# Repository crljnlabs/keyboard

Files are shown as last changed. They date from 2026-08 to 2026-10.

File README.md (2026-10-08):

# keyboard

The crljn keypad: six keys, a rotary encoder with a push button and a 1.69 inch
display, on an ESP32-S3 Super Mini. This repository holds its firmware and its
circuit board.

Over USB the keypad is a vendor-defined HID device, so no operating system
treats it as a keyboard and nothing it sends ever types into a window. What a
key does is up to the program on the PC,
[anydeck](https://github.com/crljnlabs/anydeck), whose device contract
(`docs/device-protocol.md` there) this firmware keeps to.

- What the keypad says over USB, byte for byte: [docs/hid.md](docs/hid.md)

## What the firmware does

- Reads the six keys and the encoder, and reports them to the PC.
- Tells the PC what it is made of, the display included.
- Shows a status screen of its own: the encoder's position and last direction,
  and which keys are held.
- Logs over the same USB cable, as a serial port.

Not yet: showing on the display what the PC sends.

## Building and flashing

Needs Python 3 and PlatformIO (`pio`). Everything else - the toolchain, the
libraries, esptool - PlatformIO fetches itself on the first build.

```bash
python3 scripts/flash.py
```

The everyday command: compiles, flashes the board and opens the serial monitor.
It remembers the port that worked and only asks again when that one is gone.
`-p <port>` picks a port once, `--no-monitor` leaves the monitor closed.

```bash
python3 scripts/build.py
```

Compiles only, into `build/<timestamp>/`, which is not tracked.

```bash
python3 scripts/deploy.py
```

Publishes a build that already exists as a version, `release/<version>/`, which
is tracked. It never compiles, so the bytes that were tested are the bytes that
get published. It suggests the newest build and the next minor version.

```bash
python3 release/install.py
```

Flashes a published version, the newest unless one is named; `--list` shows
them. Nothing is published yet.

## Technology

- C++ with PlatformIO and the Arduino framework, for the ESP32-S3 Super Mini
  (module ESP32-S3FH4R2: 4 MB flash, 2 MB PSRAM). The platform is pinned,
  `espressif32@6.12.0` with Arduino core 2.0.17, so a build is reproducible.
- USB through TinyUSB (`ARDUINO_USB_MODE=0`), which a vendor-defined HID
  interface needs; the serial port sits next to it on the same device.
- The display, an ST7789 panel, through TFT_eSPI, configured only through build
  flags in `platformio.ini`.

## Where things are

| | |
|---|---|
| `src/` | the firmware |
| `include/pins.h` | every GPIO the firmware touches, and why the pins do not match the schematic's net names |
| `platformio.ini` | the board, the USB setup and the display configuration |
| `docs/` | the USB protocol |
| `kicad/` | schematic, board, 3D model, gerbers and an interactive BOM |
| `scripts/` | building, flashing and publishing |
| `release/` | published versions, and the script that installs them |

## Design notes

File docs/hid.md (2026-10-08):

# USB protocol of the crljn keypad

What this firmware tells the PC about itself, and what it sends, byte for byte.

The rules behind it are not this device's own. A device that is to work with
anydeck keeps to anydeck's device contract, `docs/device-protocol.md` in the
anydeck repository (github.com/crljnlabs/anydeck): why every collection is
vendor-defined, which standard usages anydeck recognises, why the serial number
matters, and how the capability report is built, with all its defaults. This
file is the keypad's answer to it and does not repeat it.

Status in this firmware:

| | |
|---|---|
| report descriptor | offered, 120 bytes |
| report `0x01`, input | sent |
| report `0x10`, capability block | answered |
| report `0x11`, fast buttons | answered and taken, kept in flash |
| report `0x20`, display data | declared, and ignored when it arrives |

What anydeck does with each of them today is in the contract's last section.

## Identity

| | | where it comes from |
|---|---|---|
| vendor id | `0x303A` | the Arduino core's `esp32s3` variant |
| product id | `0x1001` | the Arduino core's `esp32s3` variant |
| manufacturer | `crljn.labs` | `USB_MANUFACTURER` in `platformio.ini` |
| product | `crljn-board` | `USB_PRODUCT` in `platformio.ini` |
| serial number | the chip's MAC address | the Arduino core's default |

The product and the manufacturer are set by this project. The serial number
is the chip's factory MAC address as twelve hex digits - `2884856D6EC0` on the
first unit - so every keypad has its own, which is what the contract asks for.

The vendor and product id are Espressif's generic pair, shared by many ESP32-S3
boards. That does no harm: anydeck does not pick devices by those ids, and the
serial number tells the units apart.

anydeck names a keypad after its product name when it first finds it.

## Report descriptor

120 bytes. Offered by the device at plug-in time. One vendor-defined
application collection, a vendor-defined physical collection for the keys and
one for the encoder, and standard usages on the data items inside.

```c
static const uint8_t kReportDescriptor[] = {
    0x06, 0x00, 0xFF,        // Usage Page (Vendor Defined 0xFF00)
    0x09, 0x01,              // Usage (0x01)
    0xA1, 0x01,              // Collection (Application)

    0x85, 0x01,              //   Report ID (1)

    0x06, 0x00, 0xFF,        //   Usage Page (Vendor Defined 0xFF00)
    0x09, 0x02,              //   Usage (0x02) - the keys
    0xA1, 0x00,              //   Collection (Physical)
    0x05, 0x09,              //     Usage Page (Button)
    0x19, 0x01,              //     Usage Minimum (Button 1)
    0x29, 0x06,              //     Usage Maximum (Button 6)
    0x15, 0x00,              //     Logical Minimum (0)
    0x25, 0x01,              //     Logical Maximum (1)
    0x75, 0x01,              //     Report Size (1)
    0x95, 0x06,              //     Report Count (6)
    0x81, 0x02,              //     Input (Data, Variable, Absolute)
    0x75, 0x02,              //     Report Size (2)
    0x95, 0x01,              //     Report Count (1)
    0x81, 0x03,              //     Input (Constant) - padding to a byte
    0xC0,                    //   End Collection

    0x06, 0x00, 0xFF,        //   Usage Page (Vendor Defined 0xFF00)
    0x09, 0x03,              //   Usage (0x03) - the encoder
    0xA1, 0x00,              //   Collection (Physical)
    0x05, 0x09,              //     Usage Page (Button)
    0x09, 0x07,              //     Usage (Button 7) - the encoder's click
    0x15, 0x00,              //     Logical Minimum (0)
    0x25, 0x01,              //     Logical Maximum (1)
    0x75, 0x01,              //     Report Size (1)
    0x95, 0x01,              //     Report Count (1)
    0x81, 0x02,              //     Input (Data, Variable, Absolute)
    0x75, 0x07,              //     Report Size (7)
    0x95, 0x01,              //     Report Count (1)
    0x81, 0x03,              //     Input (Constant) - padding to a byte
    0x05, 0x01,              //     Usage Page (Generic Desktop)
    0x09, 0x37,              //     Usage (Dial)
    0x15, 0x81,              //     Logical Minimum (-127)
    0x25, 0x7F,              //     Logical Maximum (127)
    0x75, 0x08,              //     Report Size (8)
    0x95, 0x01,              //     Report Count (1)
    0x81, 0x06,              //     Input (Data, Variable, Relative)
    0xC0,                    //   End Collection

    0x85, 0x10,              //   Report ID (0x10) - capability block
    0x06, 0x00, 0xFF,        //   Usage Page (Vendor Defined 0xFF00)
    0x09, 0x10,              //   Usage (0x10)
    0x15, 0x00,              //   Logical Minimum (0)
    0x26, 0xFF, 0x00,        //   Logical Maximum (255)
    0x75, 0x08,              //   Report Size (8)
    0x95, 0x3F,              //   Report Count (63)
    0xB1, 0x02,              //   Feature (Data, Variable, Absolute)

    0x85, 0x11,              //   Report ID (0x11) - fast buttons
    0x09, 0x11,              //   Usage (0x11)
    0x75, 0x08,              //   Report Size (8)
    0x95, 0x01,              //   Report Count (1)
    0xB1, 0x02,              //   Feature (Data, Variable, Absolute)

    0x85, 0x20,              //   Report ID (0x20) - display data, PC -> device
    0x09, 0x20,              //   Usage (0x20)
    0x75, 0x08,              //   Report Size (8)
    0x95, 0x3F,              //   Report Count (63)
    0x91, 0x02,              //   Output (Data, Variable, Absolute)

    0xC0,                    // End Collection
};
```

What anydeck makes of it: six keys, from the six buttons, and one rotary
encoder, from the dial and the button in the same collection.

### Why the keys and the encoder are not labelled `Keypad` and `Dial`

They were once. With the keys' collection labelled `Keypad`, macOS's keyboard
driver took the device and turned its buttons into clicks in the focused
window, although the application collection around it was vendor-defined:
macOS publishes the usage of every application *and* every physical collection,
and its keyboard driver matches on them. Vendor usages `0x02` and `0x03` keep
it out, and cost nothing - what an element is follows from the items inside a
collection, never from its label. `src/keypad_hid.cpp` has the full account.

### Listed three times on macOS

macOS lists every collection usage it finds, not only the application one, so
this device appears **three times** in `hid.enumerate()` - as usages `0x01`,
`0x02` and `0x03` on page `0xFF00` - all carrying the same path. It is one
device, listed once per collection.

## Report 0x01 — input, device to PC, 4 bytes

| Byte | Bits | Meaning |
|---|---|---|
| 0 | 7..0 | report id, always `0x01` |
| 1 | 0..5 | keys SW1..SW6, one bit each, `1` = pressed |
| 1 | 6..7 | padding, always `0` |
| 2 | 0 | encoder push button, `1` = pressed |
| 2 | 1..7 | padding, always `0` |
| 3 | 7..0 | encoder movement since the previous report, signed, `+` = clockwise |

Sent when something changed. Also sent once after start-up, as soon as the PC
has set the device up, with whatever is held at that moment - even if that is
nothing. A program that opens the device only later does not get that first
report; it asks instead. A GET_REPORT for report `0x01` answers with the keys and
the button as they are now and `0` in byte 3 - asking is not turning, and
detents not yet sent still go out with the next report. anydeck asks once,
when it opens the keypad.

Byte 3 is a **difference, not a position**. The firmware adds up detents between
reports. A report takes as many of them as fit - up to ±127 - and leaves the
rest for the next one, so a fast spin arrives in full rather than clipped. A
report counts as sent once it is queued for the endpoint; only one that could
not be queued keeps its state for another try, so no detent is lost and none
arrives twice. Apart from the first report, none is sent for a difference of
zero with no button change.

## Report 0x10 — capability block, feature, read by the PC

Declared as 63 bytes. The firmware answers whenever it is asked, with the 21
bytes it has to say rather than 63 - two entries and the end of the list. The
format allows that: a reader goes by the entries, not by the report's length.

On the wire, after the report id:

```
01 02 01 01                                     device info, 2 bytes
02 0D 18 01 F0 00 01 00 03 0E 46 01 17 01 03    display, 13 bytes
00 00                                           end of list
```

| Entry | Byte | Field | Value on this device |
|---|---|---|---|
| `0x01` device info | 0 | protocol version | `1` |
| | 1 | display entries that follow | `1` |
| `0x02` display | 0..1 | width in pixels | `280` |
| | 2..3 | height in pixels | `240` |
| | 4 | pixel format | `1`, RGB565 |
| | 5 | display index | `0` |
| | 6 | rotation the firmware applies, in 90° steps | `3` |
| | 7 | corner radius in pixels | `43` |
| | 8..9 | physical width, tenths of a millimetre | `326` |
| | 10..11 | physical height, tenths of a millimetre | `279` |
| | 12 | capability flags | `0b0000_0011` |

All 13 bytes of the display entry are sent, so no default applies anywhere.

Width and height are the panel as the firmware draws on it, after rotation `3`.
The panel itself is 240 x 280 (`TFT_WIDTH` and `TFT_HEIGHT` in
`platformio.ini`), and 280 x 240 is the same panel lying on its side; the values
come from `Display::kWidth` and `Display::kHeight`.

The physical size is the 1.69 inch panel's visible area, 32.6 by 27.9 mm in this
orientation. The corner radius of `43` was measured from a photo of the panel -
all four corners came out at 42 to 44 px - and confirmed on the device, where an
arc of that radius ran along the edge of the glass (`Display::kCornerRadius`).

The flags say the backlight can be dimmed (bit 0) and the display takes full
frames (bit 1). Both are true of the panel - the firmware dims the backlight
itself, through PWM - and neither can be reached from the PC yet: there is no
command for the brightness, and nothing receives a frame. The flags describe
the display as it is; using them is the display feed's work.

## Report 0x11 — fast buttons, feature, read and written by the PC

One byte after the report id. A bit stands for a button by its number in the
descriptor, so the contract's rule - bit n for button n + 1 - comes out as:

| Bit | Button | Element |
|---|---|---|
| 0..5 | 1..6 | keys SW1..SW6 |
| 6 | 7 | the encoder's push button |
| 7 | — | always `0` |

`1` is fast, `0` normal, and normal is what a new keypad starts with. Both wait
15 ms (`DebouncedInput`): normal until the contact has been stable that long,
fast after the first edge, which it reports at once. The encoder's turning has
no such setting: its state machine needs no waiting.

A SET_REPORT takes effect at once - a GET_REPORT straight after it answers with
what was set, bit 7 cleared - and the main loop applies it to the inputs and
stores it in flash, NVS namespace `keypad`, key `fast-buttons`. Written only
when the PC sends it, so the flash does not wear; read at every start, so the
keypad keeps the setting after a power cut, with or without a PC.

## Report 0x20 — display data, output, PC to device

Declared as 63 bytes per packet. The firmware ignores whatever arrives on it,
and the framing for pixel data and commands is not specified yet; specifying it
is part of building the display feed. A full frame of this display, 280 x 240 in
RGB565, is 134400 bytes, so it will have to arrive in pieces.

## See also

- anydeck's device contract, `docs/device-protocol.md` in the anydeck
  repository: the rules this file follows, the capability block's format with
  all its defaults, and how anydeck finds and reads a device.
- `src/keypad_hid.cpp`: the descriptor, the capability block and report `0x11`
  as the firmware builds them; `src/debounced_input.h` for the two ways a
  button is debounced.

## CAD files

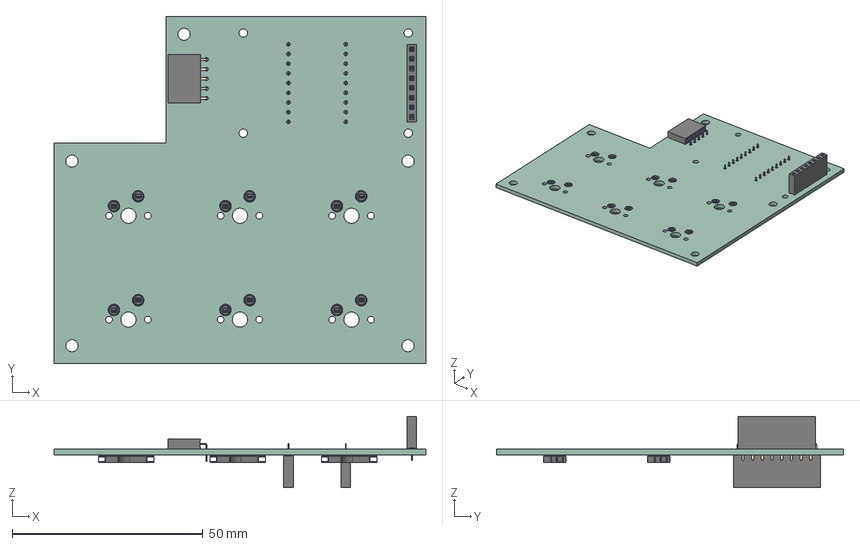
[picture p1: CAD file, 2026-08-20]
kicad/Keypad.step
97.4 x 91.0 x 18.7 mm
SW_Hotswap_Kailh_cp x 6
PinSocket_1x05_P2.54mm_Horizontal
PinSocket_1x08_P2.54mm_Vertical
PinSocket_1x09_P2.54mm_Vertical x 2
Keypad-unsaved-export-8H2TMQ_PCB

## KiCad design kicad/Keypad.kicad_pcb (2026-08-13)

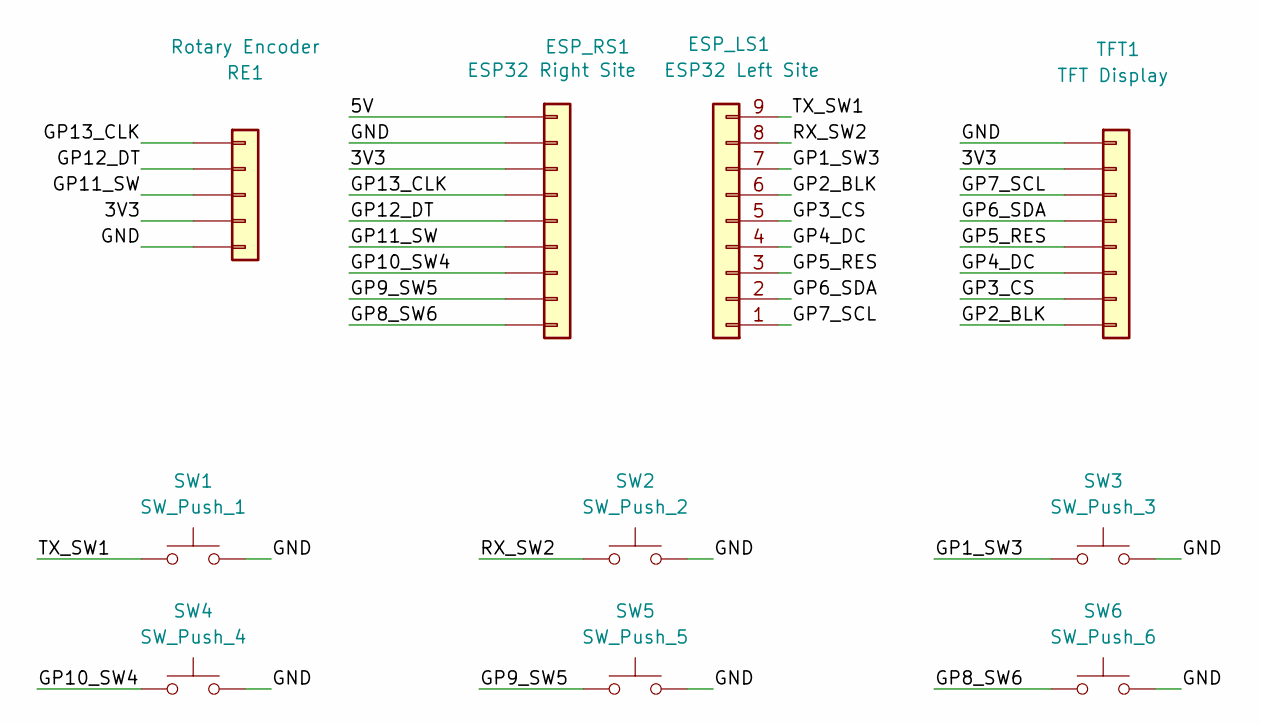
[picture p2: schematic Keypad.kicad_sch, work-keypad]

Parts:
ESP_LS1: ESP32 Left Site; PinSocket_1x09_P2.54mm_Vertical
ESP_RS1: ESP32 Right Site; PinSocket_1x09_P2.54mm_Vertical
RE1: Rotary Encoder; PinSocket_1x05_P2.54mm_Horizontal
SW1: SW_Push_1; SW_Hotswap_Kailh_MX_1.00u
SW2: SW_Push_2; SW_Hotswap_Kailh_MX_1.00u
SW3: SW_Push_3; SW_Hotswap_Kailh_MX_1.00u
SW4: SW_Push_4; SW_Hotswap_Kailh_MX_1.00u
SW5: SW_Push_5; SW_Hotswap_Kailh_MX_1.00u
SW6: SW_Push_6; SW_Hotswap_Kailh_MX_1.00u
TFT1: TFT Display; PinSocket_1x08_P2.54mm_Vertical

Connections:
/3V3: ESP_RS1.3, RE1.4, TFT1.2
/5V: ESP_RS1.1
/GND: ESP_RS1.2, RE1.5, SW1.1, SW2.1, SW3.1, SW4.1, SW5.1, SW6.1, TFT1.1
/GP1_SW3: ESP_LS1.7, SW3.2
/GP2_BLK: ESP_LS1.6, TFT1.8
/GP3_CS: ESP_LS1.5, TFT1.7
/GP4_DC: ESP_LS1.4, TFT1.6
/GP5_RES: ESP_LS1.3, TFT1.5
/GP6_SDA: ESP_LS1.2, TFT1.4
/GP7_SCL: ESP_LS1.1, TFT1.3
/GP8_SW6: ESP_RS1.9, SW6.2
/GP9_SW5: ESP_RS1.8, SW5.2
/GP10_SW4: ESP_RS1.7, SW4.2
/GP11_SW: ESP_RS1.6, RE1.3
/GP12_DT: ESP_RS1.5, RE1.2
/GP13_CLK: ESP_RS1.4, RE1.1
/RX_SW2: ESP_LS1.8, SW2.2
/TX_SW1: ESP_LS1.9, SW1.2

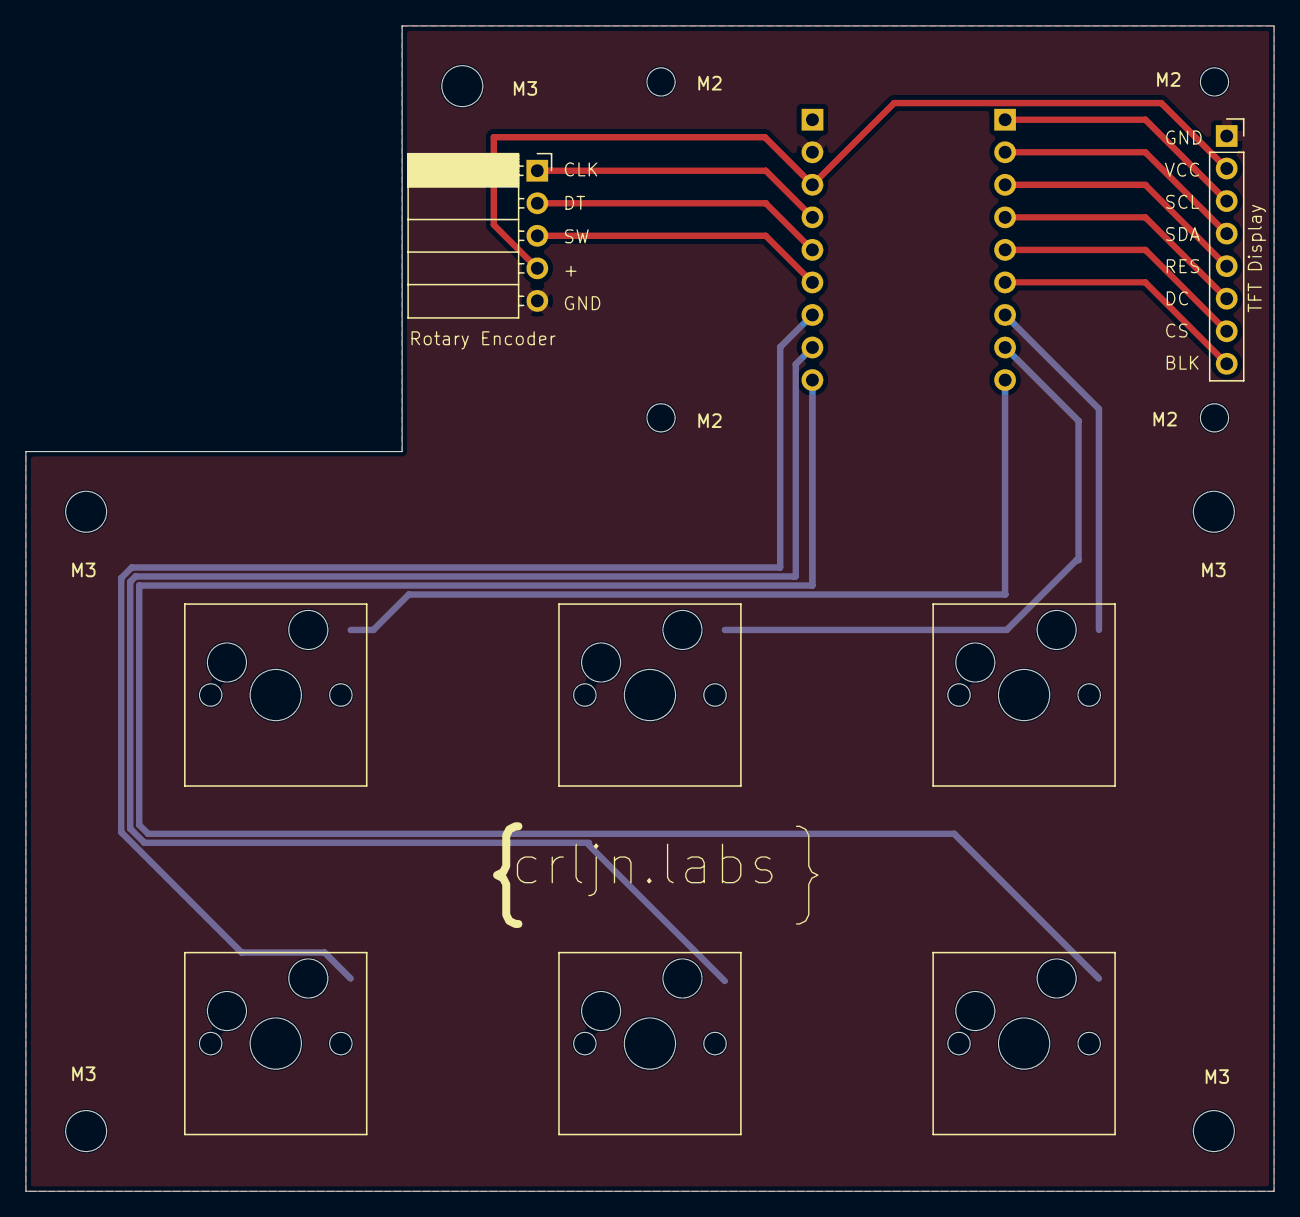
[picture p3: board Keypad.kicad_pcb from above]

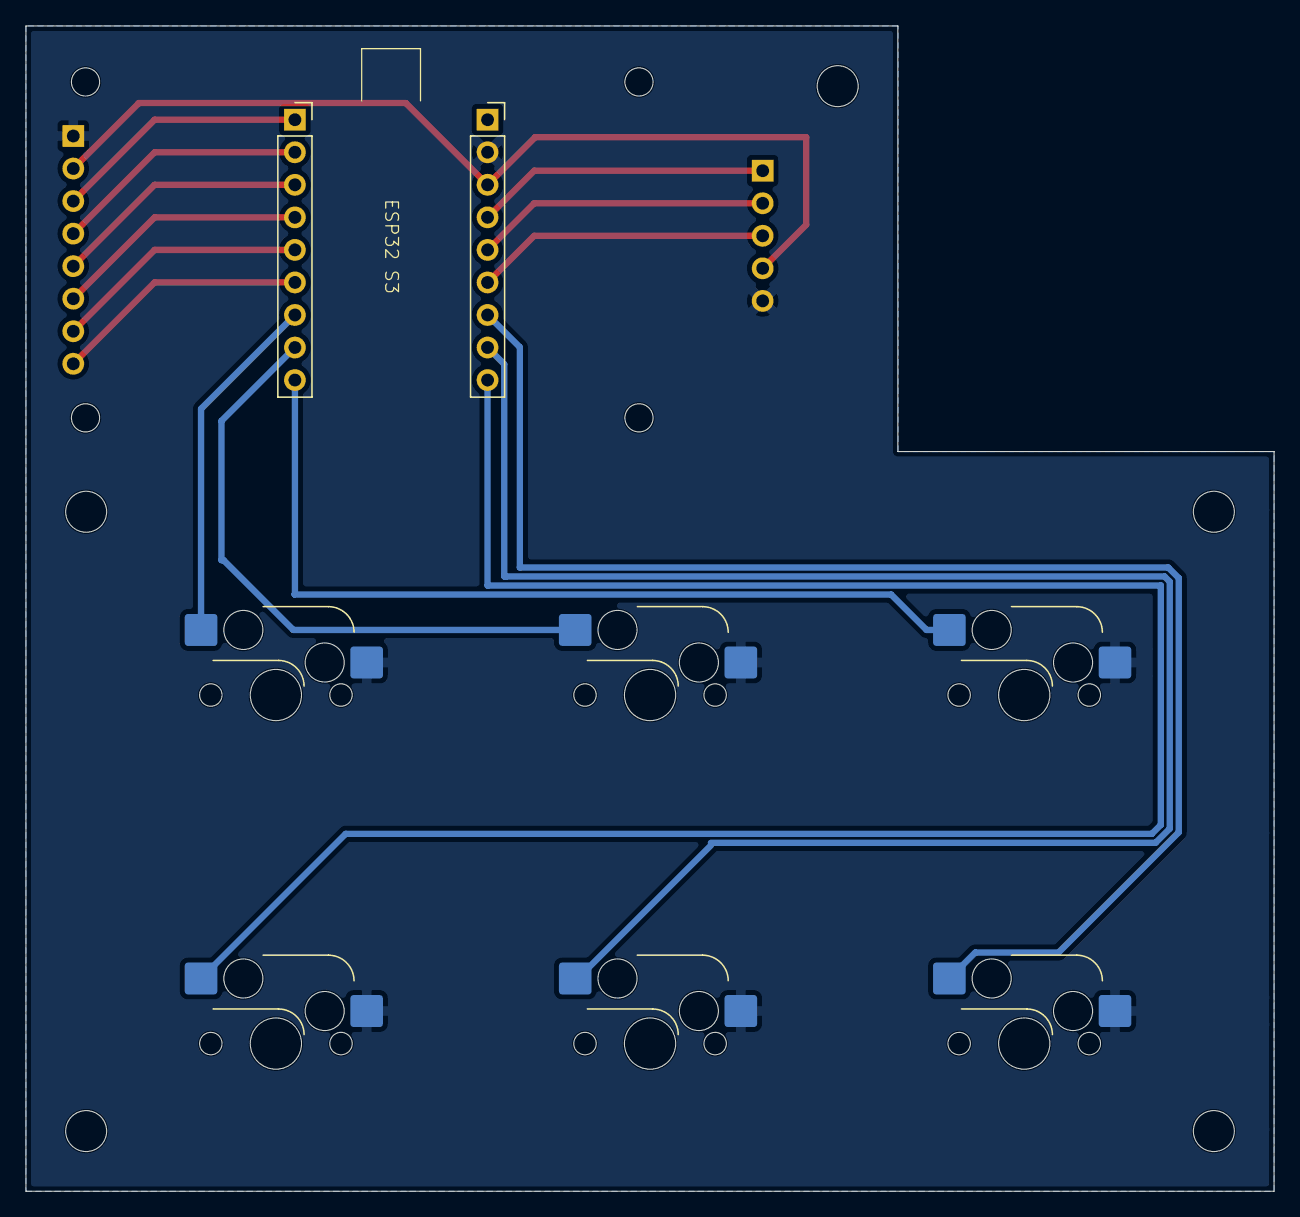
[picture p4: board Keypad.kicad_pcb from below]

Board: 2 copper layers, 97.4 x 91.0 mm, 10 parts (2 on the bottom side), 17 nets.

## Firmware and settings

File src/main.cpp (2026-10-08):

// Firmware entry point.
//
// Reads the six key switches and the rotary encoder, mirrors their state on the
// TFT status screen, and reports them to the PC over a vendor-defined USB HID
// interface. The PC can set single buttons to report at once; the keypad keeps
// that in flash. Receiving display content from the PC is not implemented yet.

#include <Arduino.h>
#include <Preferences.h>

#include "display.h"
#include "keypad_hid.h"
#include "rotary_encoder.h"
#include "status_screen.h"
#include "switches.h"

namespace {

Display display;
StatusScreen screen(display);
RotaryEncoder encoder;
Switches switches;

// Global on purpose, not a local of setup(): its constructor registers the HID
// interface, and the Arduino core starts USB in app_main - before setup() runs.
// A global constructor is the last moment at which the report descriptor can
// still be added.
KeypadHid keypadHid;

constexpr uint8_t kBacklightBrightness = 220;
constexpr uint16_t kBacklightFadeMs = 400;

// Which buttons report at once, kept in flash: the setting outlives a power cut
// and needs no PC to come back.
Preferences settings;
constexpr const char* kSettingsNamespace = "keypad";
constexpr const char* kFastButtonsKey = "fast-buttons";

// Bit n is button n + 1 of the report descriptor: SW1..SW6, then the encoder's
// click.
void applyFastButtons(uint8_t mask) {
  for (uint8_t i = 0; i < Switches::count(); ++i) {
    switches.setFast(i, mask & (1u << i));
  }
  encoder.setButtonFast(mask & (1u << Switches::count()));
}

}  // namespace

void setup() {
  Serial.begin(115200);

  display.begin();
  screen.begin();
  display.fadeBrightness(kBacklightBrightness, kBacklightFadeMs);

  keypadHid.begin();

  encoder.onRotate([](int8_t direction, int32_t position) {
    screen.onEncoderRotate(direction, position);
    keypadHid.addRotation(direction);
  });
  encoder.onButton([](bool pressed) {
    screen.onEncoderButton(pressed);
    keypadHid.setEncoderButton(pressed);
  });
  encoder.begin();

  switches.onEvent([](uint8_t index, bool pressed) {
    screen.onSwitch(index, pressed);
    keypadHid.setKey(index, pressed);
  });
  switches.begin();

  settings.begin(kSettingsNamespace, false);
  const uint8_t fast = settings.getUChar(kFastButtonsKey, 0);
  applyFastButtons(fast);
  keypadHid.setFastButtons(fast);

  Serial.printf("keypad ready: %u switches, 1 encoder, %dx%d display\n", Switches::count(),
                display.width(), display.height());
}

void loop() {
  encoder.update();
  switches.update();
  screen.update();
  keypadHid.update();

  uint8_t fast = 0;
  if (keypadHid.takeFastButtons(fast)) {
    applyFastButtons(fast);
    settings.putUChar(kFastButtonsKey, fast);
  }
}

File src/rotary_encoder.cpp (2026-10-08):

#include "rotary_encoder.h"

namespace {

// Half-step quadrature transition table (Ben Buxton, "Rotary encoder, state
// machine implementation", the half-step variant). Row = current state, column
// = the new pin levels as (B << 1) | A. A cell holds the follow-up state, with
// kDirCw / kDirCcw set in the upper bits when a detent was completed.
//
// Half-step because the encoder on this board clicks twice per quadrature
// cycle: it rests with both lines high, and again with both lines low. A
// full-step table only completes at one of the two, so it counted every second
// click. This one completes at both - one step per click.
//
// A step is still only emitted after the lines passed through the level in
// between, so a contact that rattles between two levels keeps falling back to
// the rest it came from.
constexpr uint8_t kRestHigh = 0x0;     // both lines high
constexpr uint8_t kCcwBegin = 0x1;     // out of the high rest, counter-clockwise
constexpr uint8_t kCwBegin = 0x2;      // out of the high rest, clockwise
constexpr uint8_t kRestLow = 0x3;      // both lines low
constexpr uint8_t kCwBeginLow = 0x4;   // out of the low rest, clockwise
constexpr uint8_t kCcwBeginLow = 0x5;  // out of the low rest, counter-clockwise

constexpr uint8_t kDirCw = 0x10;
constexpr uint8_t kDirCcw = 0x20;
constexpr uint8_t kStateMask = 0x0f;
constexpr uint8_t kDirMask = 0x30;

const uint8_t kTransitions[6][4] = {
    // kRestHigh
    {kRestLow, kCwBegin, kCcwBegin, kRestHigh},
    // kCcwBegin
    {static_cast<uint8_t>(kRestLow | kDirCcw), kRestHigh, kCcwBegin, kRestHigh},
    // kCwBegin
    {static_cast<uint8_t>(kRestLow | kDirCw), kCwBegin, kRestHigh, kRestHigh},
    // kRestLow
    {kRestLow, kCcwBeginLow, kCwBeginLow, kRestHigh},
    // kCwBeginLow
    {kRestLow, kRestLow, kCwBeginLow, static_cast<uint8_t>(kRestHigh | kDirCw)},
    // kCcwBeginLow
    {kRestLow, kCcwBeginLow, kRestLow, static_cast<uint8_t>(kRestHigh | kDirCcw)},
};

}  // namespace

void RotaryEncoder::begin() {
  // The module carries its own pull-ups, but enabling the internal ones keeps
  // the lines defined even when a bare encoder without the breakout is wired
  // up.
  pinMode(pins::kEncoderA, INPUT_PULLUP);
  pinMode(pins::kEncoderB, INPUT_PULLUP);
  button_.begin(pins::kEncoderButton);

  // Start at the rest the knob is actually in. Either is a detent, and the
  // table only leaves a rest through the level in between, so starting at the
  // other one would cost the first click.
  state_ = sampleLevels() == 0 ? kRestLow : kRestHigh;

  attachInterruptArg(digitalPinToInterrupt(pins::kEncoderA), onQuadratureEdge, this, CHANGE);
  attachInterruptArg(digitalPinToInterrupt(pins::kEncoderB), onQuadratureEdge, this, CHANGE);
}

void IRAM_ATTR RotaryEncoder::onQuadratureEdge(void* arg) {
  static_cast<RotaryEncoder*>(arg)->decode();
}

uint8_t IRAM_ATTR RotaryEncoder::sampleLevels() {
  // The transition table is written for (B << 1) | A. On this board CLK and DT
  // reach the MCU the other way round, which made a clockwise turn count down.
  // Sampling the two swapped fixes the direction at its source, so both the
  // table and the reported sign stay canonical - negating the result afterwards
  // would work too, but then every reader has to know about the correction.
  return (digitalRead(pins::kEncoderA) << 1) | digitalRead(pins::kEncoderB);
}

void IRAM_ATTR RotaryEncoder::decode() {
  const uint8_t levels = sampleLevels();
  const uint8_t next = kTransitions[state_ & kStateMask][levels];
  state_ = next & kStateMask;

  const uint8_t direction = next & kDirMask;
  if (direction == 0) {
    return;
  }

  portENTER_CRITICAL_ISR(&lock_);
  pendingSteps_ += (direction == kDirCw) ? 1 : -1;
  portEXIT_CRITICAL_ISR(&lock_);
}

void RotaryEncoder::update() {
  // Take the whole batch at once so no step decoded while reporting is lost.
  portENTER_CRITICAL(&lock_);
  const int32_t steps = pendingSteps_;
  pendingSteps_ = 0;
  portEXIT_CRITICAL(&lock_);

  // Report every detent separately, so a consumer that maps detents to key
  // repeats sees the same count regardless of how long the loop was busy.
  if (steps != 0) {
    const int8_t direction = steps > 0 ? 1 : -1;
    const int32_t count = steps > 0 ? steps : -steps;
    for (int32_t i = 0; i < count; ++i) {
      position_ += direction;
      if (rotationCallback_) {
        rotationCallback_(direction, position_);
      }
    }
  }

  const DebouncedInput::Event event = button_.update();
  if (event != DebouncedInput::Event::kNone && buttonCallback_) {
    buttonCallback_(event == DebouncedInput::Event::kPressed);
  }
}

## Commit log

2026-08-13 Initialize program
    [Keypad-B_Cu.gbr, Keypad-B_Mask.gbr, Keypad-B_Paste.gbr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]
2026-08-20 add step file
    [Keypad.step]
2026-08-23 feat: read the switches and encoder, and show them on the display
    Brings the hardware up: the six key switches, the rotary encoder with its
    push button, and the ST7789 panel, each behind a class that hides how the
    part is wired and exposes what it does.
    pins.h every GPIO the firmware touches, in one place
    DebouncedInput one active-low contact, debounced by sampling
    Switches the six keys, reporting press/release events
    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
2026-08-24 feat: report keys and encoder to the PC over vendor-defined HID
    Adds the USB interface the anydeck application reads. The device is one
    vendor-defined application collection, so no operating system claims it
    and no key press is injected into whatever window happens to be focused.
    Inside that collection every item uses a standard usage, so software that
    has never heard of this device can still tell the six keys and the encoder
    apart. The byte layouts are specified in hid.md.
    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
2026-10-01 fix: the first counter-clockwise detent after power-up counts
    begin() seeded the decoder's state with the pin levels it read. Levels and
    states are different things that happen to share numbers: at a detent both
    lines are high, level 3, and 3 in the transition table is kCwNext - a
    clockwise turn already under way. So the first counter-clockwise detent after
    every power-up or reset read as that turn being undone, and nothing was
    reported; two of them came out as one.
    The decoder now starts where the table rests between detents, kStart,
    whatever the lines read.
    Checked with the real rotary_encoder.cpp compiled on the host against a
    stand-in for the Arduino calls, feeding it the pin sequences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
    [rotary_encoder.cpp]
2026-10-02 fix: a rotation reaches the PC once, even when the host acknowledges late
    USBHID::SendReport() queues the report and then waits up to 100 ms for the
    host to collect it. When that wait runs out it answers false - with the
    report already queued and on its way. update() took false for "nothing went
    out", kept the rotation, and sent it again on the next pass: the PC got the
    same detents twice. Waiting longer would only make it rarer and hold the loop
    longer.
    The report is now handed to tud_hid_n_report() directly, which queues it and
    answers at once. False there really means nothing went out - the endpoint is
    still busy or the host is not listening - and only then is the state kept for
    the next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
    [keypad_hid.cpp]
2026-10-02 feat: the keypad calls itself crljn-board over USB
    The firmware never named the device, so the Arduino core used the board
    definition's name for the USB product string: "Espressif ESP32-S3-DevKitC-1-N8
    (8 MB QD, No PSRAM)" - the wrong board, and what anydeck showed as the name of
    every new keypad.
    USB_PRODUCT is now set in the build flags. The core only falls back to the
    board's name when it is not defined. The manufacturer string and the serial
    number, which the core derives from the chip's MAC address, stay as they were -
    so the identity anydeck stores a keypad under does not change, only the name a
    newly found one is given.
    Checked in the build: the define reaches the compiler as
    USB_PR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
2026-10-02 docs: hid.md describes this keypad, the rules live in anydeck
    The rules any device keeps to - vendor-defined collections, standard usages
    inside, identity, the capability report's format and defaults - are anydeck's
    device contract now, docs/device-protocol.md in the anydeck repository. This
    file keeps what only this keypad says, and corrects what the old one got wrong:
    - status: what the firmware does with each report, and nothing claimed for
    anydeck that it does not do
    - the collection labels are vendor usages because macOS's keyboard driver took
    the device while they were not, not because nothing reads them
    - the USB identity and where each part of it comes from
    - the one input repor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
2026-10-02 docs: the backlight is on GPIO4, not GPIO2
    GPIO2 is the display's DC line (TFT_DC=2 below). include/pins.h has the
    backlight as kTftBacklight = 4, and that is the pin the Display class attaches
    its PWM channel to.
2026-10-02 docs: a README that says what the keypad is and how to flash it
    The README was a heading. It now says what the keypad is and that anydeck's
    device contract is what it keeps to, what the firmware does and does not do
    yet, how the four scripts are used, and where things are.
    The firmware's technology - C++ with PlatformIO for the ESP32-S3 Super Mini -
    was written down in anydeck's requirements. It is this repository's decision,
    so it is here now, with the pinned platform and the USB and display stacks.
2026-10-02 docs: releases are made by deploy.py, install.py says so
    install.py pointed at build.py, both in its docstring and in the message it
    prints when there is nothing to install. build.py only compiles into build/;
    publishing a build to release/ is deploy.py's job.
2026-10-03 fix: no click is lost after power-up, wherever the knob rests
    The encoder on this board clicks twice per quadrature cycle: it rests with both
    lines high, or with both low. The previous fix started the decoder at kStart,
    which only fits the first. Started with both lines low, the first step in
    either direction took three clicks instead of two - before that fix as well.
    begin() now starts at a new state, kMiddle, when both lines are low: halfway
    through a cycle with no direction known yet, which kCwNext and kCcwNext, the
    table's own "both low" states, each already assume. The first step then comes
    at the next rest with both lines high, where every later step comes too.
    Simulated on the PC wi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
    [rotary_encoder.cpp]
2026-10-03 revert: the encoder starts at kStart again, whatever the lines read
    This reverts 8d55c31 ("fix: no click is lost after power-up, wherever the knob
    rests"). On the real keypad the encoder counted nonsense with it, and before it
    counted right - so it goes, the header comment and the line in docs/hid.md with
    it, until what happened on the hardware is understood. The simulation it was
    checked against did not show it, which says the simulation assumed something
    about this encoder that is not true.
    [rotary_encoder.cpp]
2026-10-03 feat: the keypad says crljn.labs made it, not Espressif
    The USB manufacturer string names who made the device, and the Arduino core's
    default named who made its chip - "Espressif Systems", which the vendor id
    0x303A says already. USB_MANUFACTURER is crljn.labs now, as the LICENSE has
    it, set next to the product name in platformio.ini. docs/hid.md says so.
    Checked: the build carries both strings.
2026-10-03 fix: flashing goes straight to download mode on the board's own USB port
    flash.py first let esptool reset the board through the app's own USB port.
    With this firmware that never reached the bootloader: every flash sat through
    a long "Connecting...", failed, and then said "the app is most likely crashing
    and tearing its USB port down" - which it was not - before the 1200 baud touch
    did the job. On the board's own port the touch comes first now. A port that is
    not the board's own, a USB-to-UART bridge on another board, is still tried
    directly first, and its failure is reported as what it is.
    Checked with the ports and esptool stood in, no hardware: the app's port goes
    straight to download mod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
2026-10-03 feat: the encoder counts one step per click
    The encoder clicks twice per quadrature cycle - it rests with both lines
    high and again with both low - and the full-step table only completed a
    step at one of the two, so every second click was lost. The half-step
    variant of the same table completes at both. begin() starts at whichever
    rest the knob is in.
    Simulated on the PC against the previous table, position after each of
    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
2026-10-04 feat: the keypad answers when asked where it stands
    A GET_REPORT for input report 0x01 - which the Arduino core routes to
    _onGetFeature like every GET_REPORT - now answers with the keys and the
    encoder button as they are, and 0 for the rotation: asking is not turning,
    and detents not yet sent still go with the next report. anydeck asks once
    when it opens the keypad, so a program that starts late knows what is held.
2026-10-08 feat: single buttons can report at once, set by the PC and kept in flash
    Feature report 0x11 holds one bit per button, bit n for button n + 1: the six
    keys and the encoder's click. A fast button reports its first edge straight
    away and ignores the contact for the 15 ms after it, instead of waiting until
    the contact has been stable for 15 ms. The bounce is swallowed either way; a
    fast press arrives 15 ms sooner, and a glitch on the line counts as a press.
    The PC reads the report and sets it. The keypad takes a new setting at once,
    so reading it back shows what took effect, applies it from the main loop and
    stores it in NVS, so it survives a power cut without a PC. Nothing changes
    until a PC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
    [debounced_input.h, keypad_hid.cpp, main.cpp]
2026-10-12 feat: the display takes what the PC sends - report 0x20 with rectangles, show, brightness
    The PC draws, the device shows. Report 0x20 now carries rectangles of
    RGB565 pixels, raw or PackBits, numbered data packets, "show" to make what
    arrived appear at once, the backlight's brightness, and "own screen" to
    hand the panel back to the status screen. Packets are decoded on the USB
    task into a frame buffer in PSRAM; the main loop pushes the changed area at
    "show", so drawing over SPI never holds up USB. The capability flags say so:
    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
2026-10-12 docs: the Linux note in keypad_hid.h says what is read and what is tried
    The comment claimed Linux maps the buttons to input events whatever the
    collections around them, and an uncommitted rewrite claimed the opposite
    detail. Neither was tried on Linux. Reading the kernel's hid-input, it wants
    a collection with an input usage before it makes an input device at all, and
    this descriptor has none - so the note now says that, as a reading, and
    points at the test in anydeck's docs/testing.md.
2026-10-19 feat: the display puts pieces together - pictures with a place, an opacity and a share shown
    Report 0x20 now carries pieces instead of pixel rectangles: the PC sends
    pictures with transparency and where each goes, the device keeps them in
    PSRAM and lays them over each other in the order of their ids. A moved
    piece is a new place, a faded one a new opacity, a bar's or ring's value
    the share of its fill - from one side or clockwise around a centre. The
    main loop puts together only the area that changed and frees replaced
    pieces once nothing draws with them. Capability flags: bit 5 for pieces,
    the rectangle bits are gone.
2026-10-19 feat: the keypad says over serial why it started last, how much memory is free and what the display feed refused
    For finding out why it drops off the USB now and then: a crash, a
    watchdog or too little power shows as the reason it started.
2026-10-20 fix: input reports go out from the main loop again, without waiting for gaps
    Neither sending on the USB task nor waiting for a gap in the display
    packets kept the keypad on the bus; the old USB driver was the cause.
    What stays is a stress build (KEYPAD_USB_STRESS=1): a report every
    10 ms, to check that reports and display packets can cross.
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2026-10-20 feat: the serial report names a reset over USB, a power glitch and a locked-up processor
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2026-11-05 feat: the display is set up in the sketch, through LovyanGFX
    The anydeck library drives displays through LovyanGFX now, configured at
    run time: the panel, its size and its pins move from TFT_eSPI's build flags
    into src/main.cpp, taken from include/pins.h. The workaround for TFT_eSPI's
    SPI port on the S3 goes with it.
    Needs the anydeck library's feat/multiple-displays.
